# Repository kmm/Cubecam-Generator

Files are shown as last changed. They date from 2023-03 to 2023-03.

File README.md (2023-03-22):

# Cubecam-Generator

---
> OpenSCAD Cubular Camera Module Housing Generator

## Overview
OpenSCAD script to generate cubical "science camera" style housings for the common ~40x40mm board-level USB camera modules that can be found on the Bay site and the River site.
Some of these modules are quite nice, with 4K and autofocus, and this makes little 3D printable houses for them.  

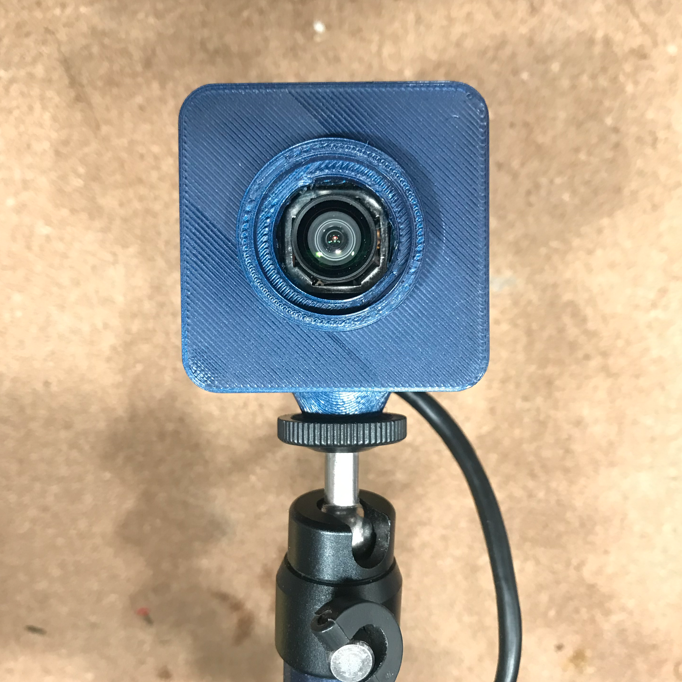
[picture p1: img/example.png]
Example Housing
  

## Usage

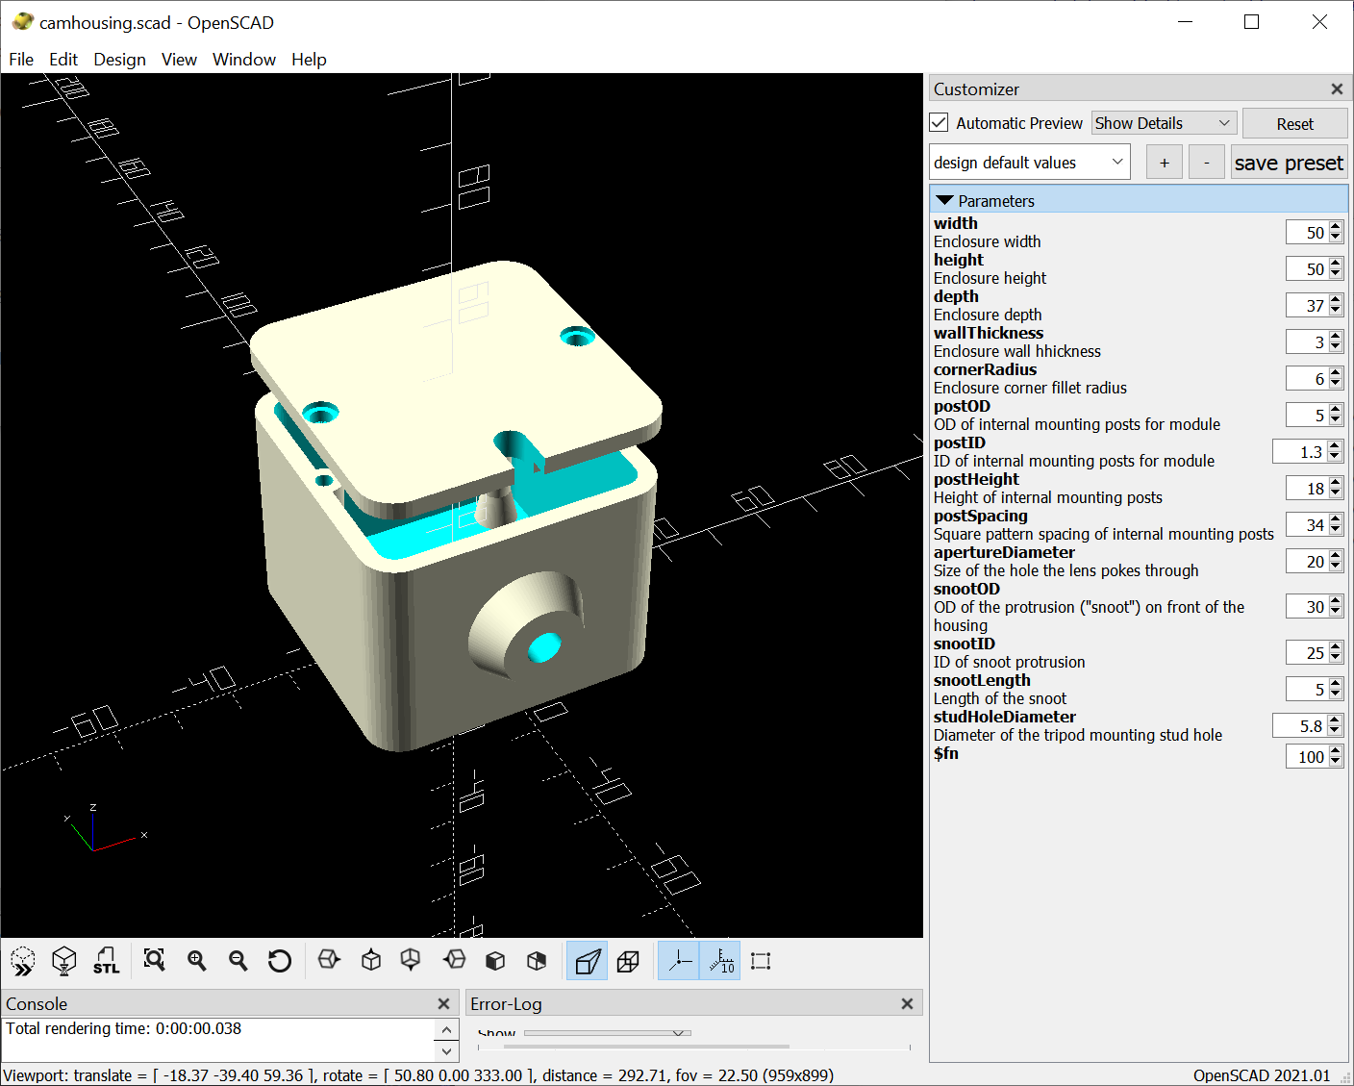
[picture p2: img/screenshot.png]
  

Install [OpenSCAD](https://openscad.org) and the [Round-Anything Library](https://github.com/Irev-Dev/Round-Anything).

Most parameters you need are exposed in the OpenSCAD customizer, modify them as you see fit to match your camera module and lens requirements.

I recommend printing this "face up" with internal supports for best outward appearance. The internal mounting posts can be a bit of a pain this way.

With PETG the layer bonds are robust enough that a "standard" 1/4-20 style tripod stud can be screwed directly into the plastic without splitting it. 
If printing in PLA, I recommend making the tripod stud hole oversized and pushing a knurled brass insert into it. Overall PETG is the way to go if you have it.

**Brass inserts can be found using the search incantation "1/4-20 threaded heat set insert" on the River site.**

## References
[OpenSCAD](https://openscad.org/)

[Round-Anything Library](https://github.com/Irev-Dev/Round-Anything)

## License

MIT

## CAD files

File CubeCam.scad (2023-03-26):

include <Round-Anything/polyround.scad>

// Enclosure width
width = 50;
// Enclosure height
height = 50;
// Enclosure depth
depth = 37;
// Enclosure wall hhickness
wallThickness = 3;
// Enclosure corner fillet radius
cornerRadius = 6;
// OD of internal mounting posts for module
postOD = 5;
// ID of internal mounting posts for module
postID = 1.3;
// Height of internal mounting posts
postHeight = 18;
// Square pattern spacing of internal mounting posts
postSpacing = 34;
// Size of the hole the lens pokes through
apertureDiameter = 20;
// OD of the protrusion ("snoot") on front of the housing
snootOD = 30;
// ID of snoot protrusion
snootID = 25;
// Length of the snoot
snootLength = 5;
// Diameter of the tripod mounting stud hole
studHoleDiameter = 5.8;

hps = postSpacing / 2;
posts = [[hps, hps], [hps, -hps], [-hps, -hps], [-hps, hps]];

dimX = width/2;
dimY = height/2;
dimZ = depth;

intDimX = dimX - wallThickness;
intDimY = dimY - wallThickness;
intCornerRadius = cornerRadius - wallThickness;
$fn = 100;
difference() {
    union() {
        difference() {
            // Extrude the housing
            linear_extrude(dimZ) {
                polygon(polyRound([
                  [dimX, dimY, cornerRadius],
                  [dimX, -dimY, cornerRadius],
                  [-dimX, -dimY, cornerRadius],
                  [-dimX, dimY, cornerRadius]
                ],10));
            };
            
            // Cut the interal volume
            translate([0, 0, wallThickness]) {
                linear_extrude(dimZ-wallThickness+1) {
                    polygon(polyRound([
                      [intDimX, intDimY, intCornerRadius],
                      [intDimX, -intDimY, intCornerRadius],
                      [-intDimX, -intDimY, intCornerRadius],
                      [-intDimX, intDimY, intCornerRadius]
                    ],10));
                };
            }; 
        };

        for(post = posts) {
            echo(post);
            translate([post[0], post[1], wallThickness]) {
                difference() {
                    union() {
                        cylinder(postHeight, d = postOD);
                        cylinder(postHeight/3, d1 = postOD * 1.5, d2 = postOD);
                    };
                    cylinder(postHeight+1, d=postID);
                };
            };
        };

        // Cover screw mounting ears
        translate([-intDimX, 0, dimZ-5]) { 
                cylinder(5, d=wallThickness*1.99);
        };
        translate([intDimX, 0, dimZ-5]) { 
            cylinder(5, d=wallThickness*1.99);
        };
        // Snoot
        difference() {
            translate([0, 0, -snootLength])
                cylinder(snootLength, d=snootOD);
            translate([0, 0, -snootLength-1])
            cylinder(snootLength, d=snootID);
        };
        // Tripod Mount
        translate([0, -dimY, dimZ/2]) {
            rotate([90, 0, 0]) {
                difference() {
                    cylinder(h=6, d1=20, d2=14);
                    cylinder(h=15, d=studHoleDiameter);
                }
            }
        }
    };
    // Cover screw holes
    translate([-intDimX, 0, dimZ-5]) { 
        cylinder(6, d=2.8);
    };
    translate([intDimX, 0, dimZ-5]) { 
        cylinder(6, d=2.8);
    };    
    // Cut the aperture hole
    translate([0, 0, -wallThickness]) {
        cylinder(wallThickness*2.1, d=apertureDiameter);
    };       
};

// Cover
translate([0, 0, dimZ + 10]) {
    difference() {
        union() {    
            difference() {
                linear_extrude(3) {
                    polygon(polyRound([
                      [dimX, dimY, cornerRadius],
                      [dimX, -dimY, cornerRadius],
                      [-dimX, -dimY, cornerRadius],
                      [-dimX, dimY, cornerRadius]
                    ],10));
                };
                
                // cover screw holes
                translate([-intDimX, 0, 0]) {
                    cylinder(5, d=3.5);   
                };
                translate([intDimX, 0, 0]) {
                    cylinder(5, d=3.5);   
                };
                translate([intDimX, 0, 2]) {
                    cylinder(5, d=5.5);   
                };
                translate([-intDimX, 0, 2]) {
                    cylinder(5, d=5.5);   
                };           
            };
            translate([0,0,-2]) {
                difference() {
                     linear_extrude(2) {
                        polygon(polyRound([
                          [intDimX-0.25, intDimY-0.25, intCornerRadius],
                          [intDimX-0.25, -intDimY+0.25, intCornerRadius],
                          [-intDimX+0.25, -intDimY+0.25, intCornerRadius],
                          [-intDimX+0.25, intDimY-0.25, intCornerRadius]
                        ],10));
                    };
                    // internal cutout for lip
                    translate([0,0,-0.01]) {
                        linear_extrude(2) {
                            polygon(polyRound([
                              [intDimX-1.5, intDimY-1.5, intCornerRadius],
                              [intDimX-1.5, -intDimY+1.5, intCornerRadius],
                              [-intDimX+1.5, -intDimY+1.5, intCornerRadius],
                              [-intDimX+1.5, intDimY-1.5, intCornerRadius]
                            ],10));
                        };
                    };
                    translate([-intDimX, 0, -3]) { 
                        cylinder(5, d=wallThickness*3);
                    };
                    translate([intDimX, 0, -3]) { 
                        cylinder(5, d=wallThickness*3);
                    };            
                };
            };
        };
        // "mouse hole" for USB cable exit
        translate([0, -intDimY+wallThickness, -3]) {
            union() {
                cylinder(15, d=5);
                translate([0, -5, 0]) {
                    cube([5, 10, 15], center=true);
                };
            };
        };
    };
};

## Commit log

2023-03-22 Update CubeCam.scad
    Minor update to script to add parameterized stud hole
    [CubeCam.scad]
2023-03-26 Update CubeCam.scad
    Changed cap locking feature to be a lip rather than solid protrusion for better filament usage efficiency.
    [CubeCam.scad]
